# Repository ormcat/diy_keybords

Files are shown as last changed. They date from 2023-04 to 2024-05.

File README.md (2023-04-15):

ErgoFine
====

## 特徴
- 左右分割
- 60%
- カラムスタッカード
- ロープロファイル (Kailh Choc V1 専用)
- 狭ピッチ (18x17 MBK キャップのサイズ)

## 設計のポイント

数字行を設け、キー数に余裕をもたせたロープロファイルな 60% キーボードです。

FR4 とアクリルを積層し、硬い打鍵感を目指しました。
スイッチプレートと基盤の間にはシリコンシートを挟めると音が落ち着くかもしれません。

※基盤製造後に KiCad データを若干調整したため、なにかしら不備があるかもしれません。

---

Designed by ormcat

基盤は [自作キーボード設計入門](https://booth.pm/ja/items/1044084) を読みながら設計しました。  
KiCad シンボル、フットプリントは [foostan/kbd](https://github.com/foostan/kbd) を利用しました。

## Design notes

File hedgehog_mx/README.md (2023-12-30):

Hedgehog (MX)
=======

DIY keyboard "Hedgehog"

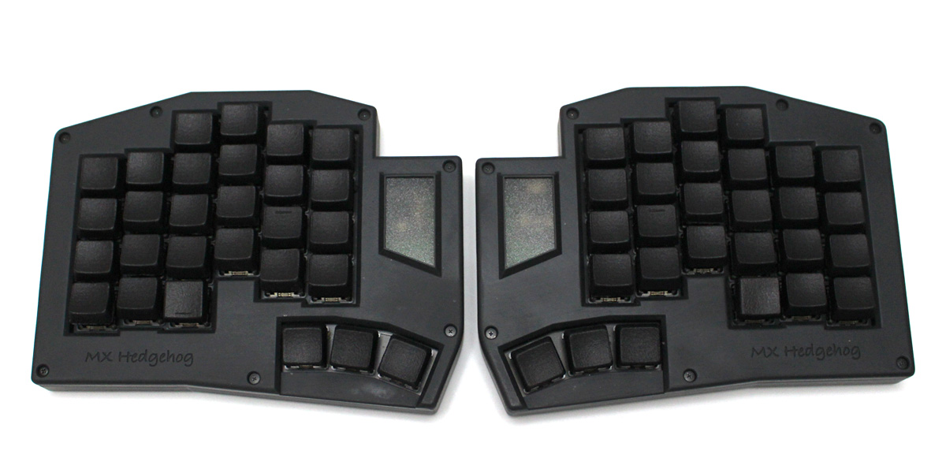
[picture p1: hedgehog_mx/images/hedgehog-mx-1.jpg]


---

## Feature

- Small key pitch (17x16)
- Split
- Size : 60% (56 keys)
- Layout : Coloumn staggered
- Controller board : Waveshare RP2040-Zero
- - Supported firmware : [QMK Firmware](https://docs.qmk.fm/#/) and Vial
- Gasket mount like 3D Printed case

## PCB Image

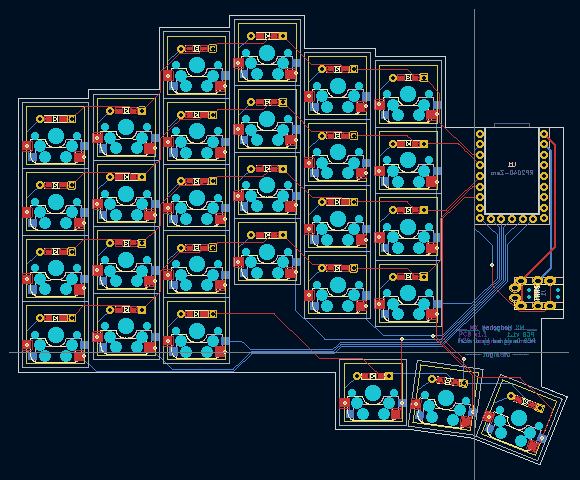
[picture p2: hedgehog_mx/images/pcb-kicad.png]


Designed by KiCad

## CaseImage

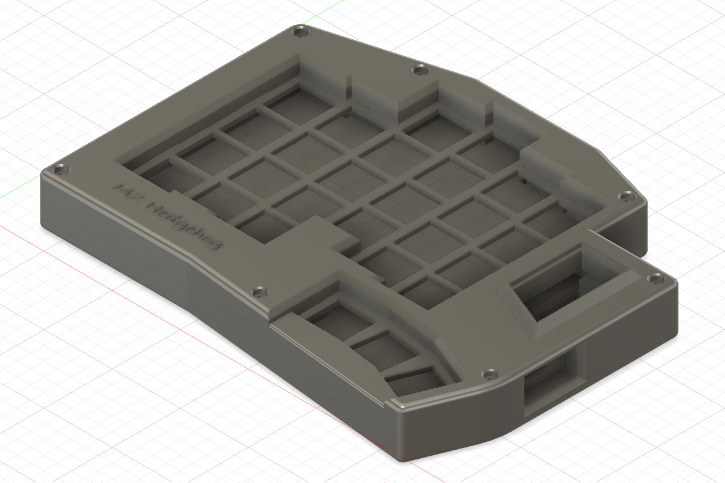
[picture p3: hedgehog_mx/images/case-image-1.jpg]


Designed by FUSION360

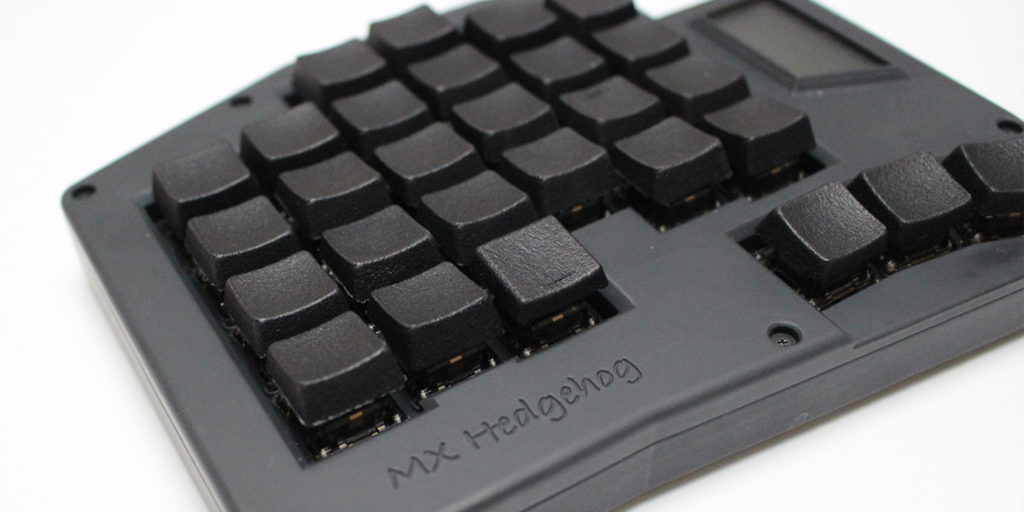
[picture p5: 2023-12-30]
hedgehog_mx/images/hedgehog-mx-4.jpg

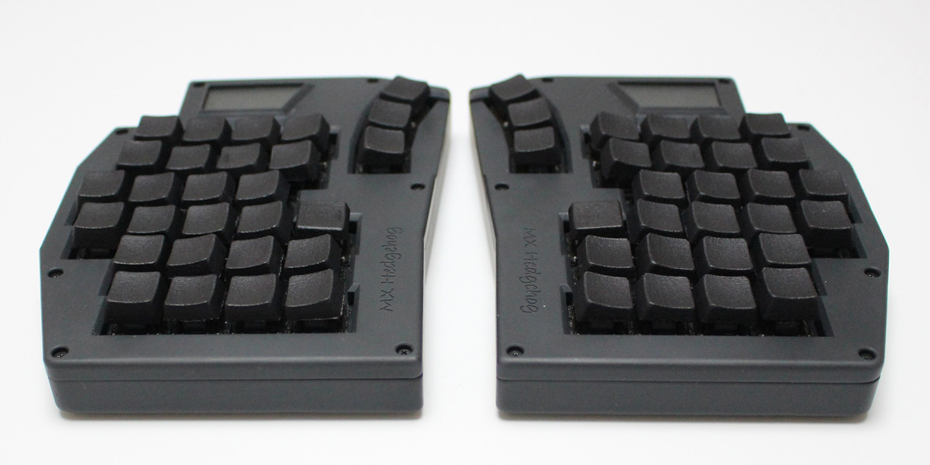
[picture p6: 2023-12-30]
hedgehog_mx/images/hedgehog-mx-2.jpg

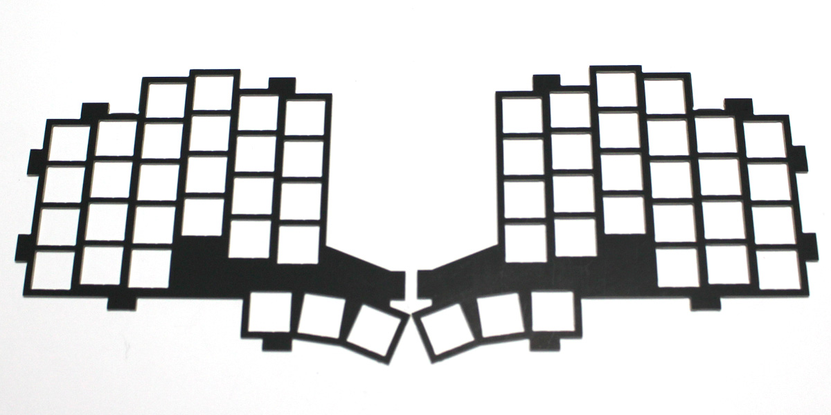
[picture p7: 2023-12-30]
hedgehog_mx/images/switch-plate.jpg

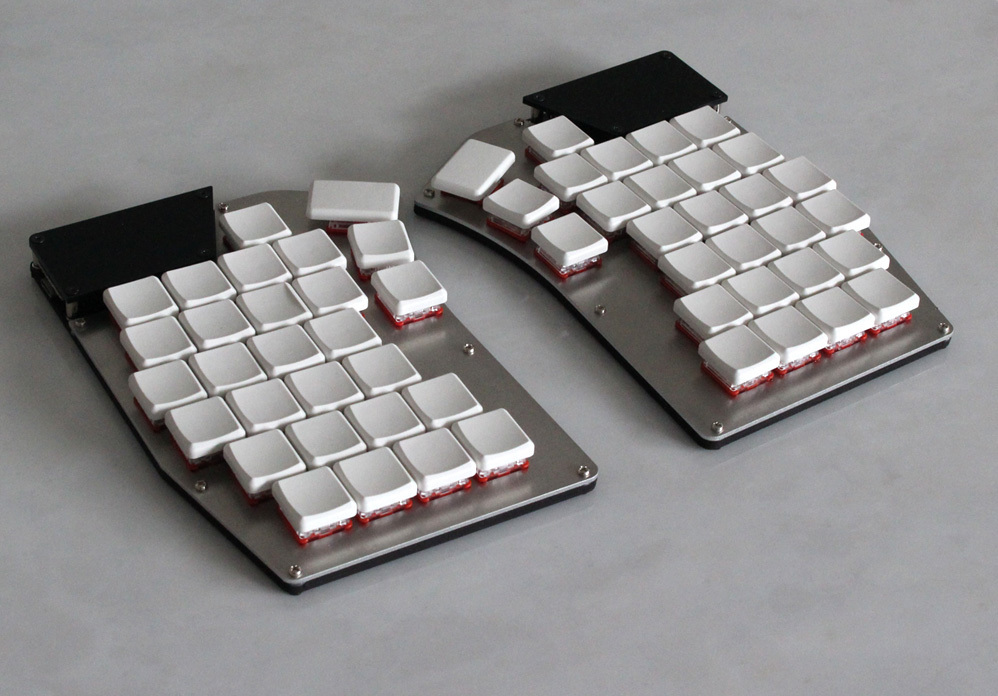
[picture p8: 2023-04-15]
ergo_file/Image/ergofine.jpg

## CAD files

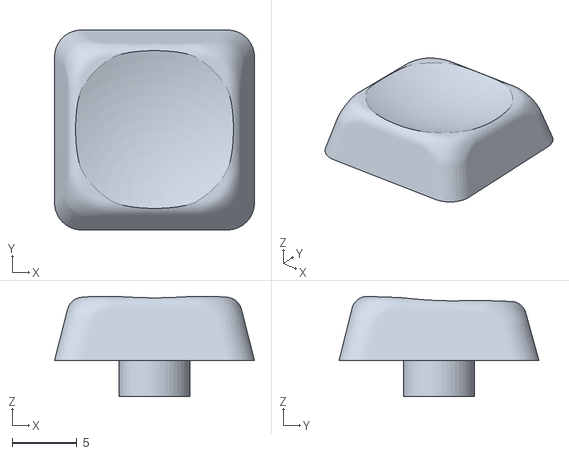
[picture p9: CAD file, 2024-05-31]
3dprinted_keycaps/original-keycap.stl
15.5 x 15.5 x 7.77

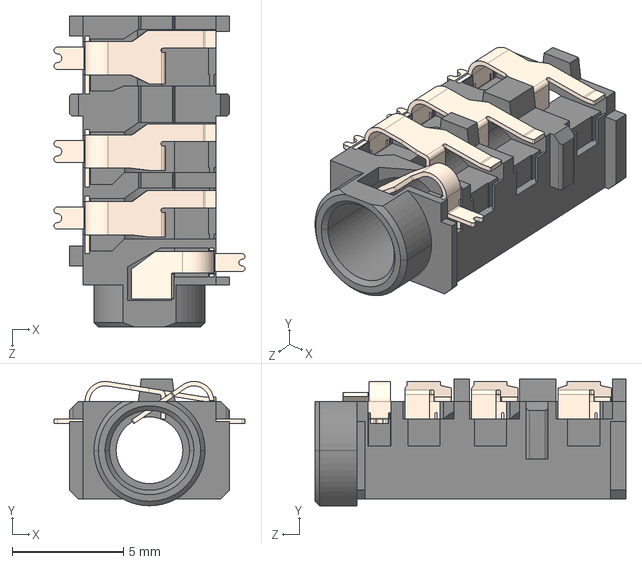
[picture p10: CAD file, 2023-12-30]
ergo_file/Pcb/@lib/Keebio-Parts.pretty-master/3dmodels/CUI_SJ-43614-SMT-TR.step
8.60 x 5.70 x 14.0 mm

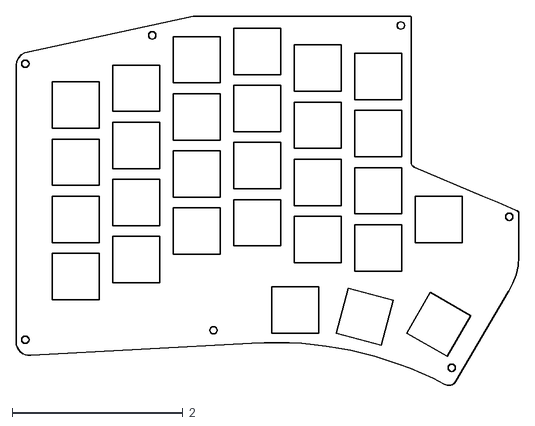
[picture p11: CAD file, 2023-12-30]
ergo_file/PlateData/ErgoFine-SwitchPlate.dxf
5.89 x 4.33

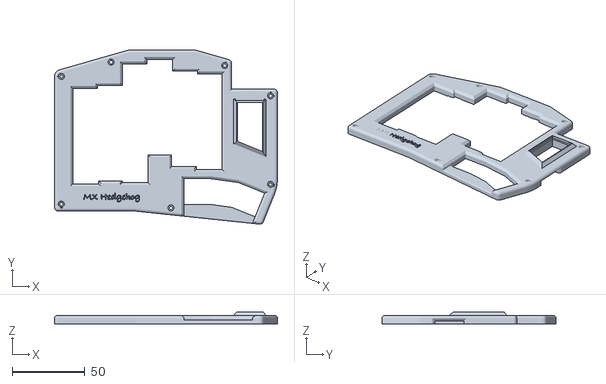
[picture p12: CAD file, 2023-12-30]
hedgehog_mx/case/HedgehogMx-Left-Top.stl
153.5 x 120.0 x 8.50

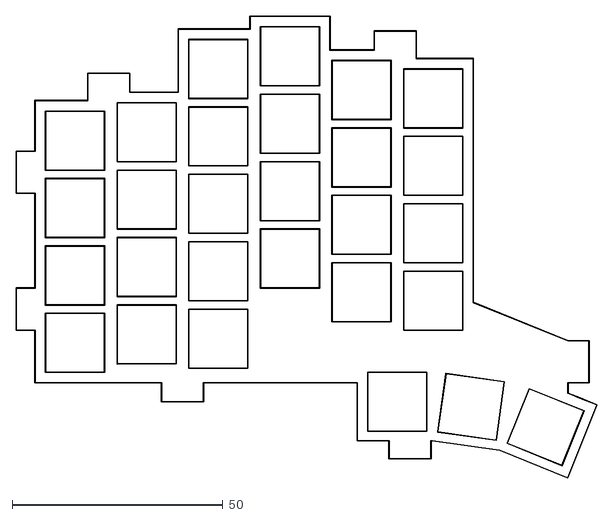
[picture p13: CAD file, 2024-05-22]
hedgehog_mx/plate/Hedgehog-Edge_Cuts.dxf
137.9 x 109.6

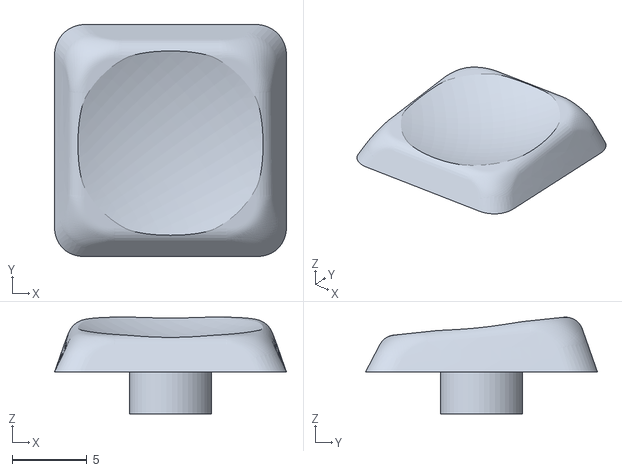
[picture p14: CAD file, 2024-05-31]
3dprinted_keycaps/original-keycap-thumb.stl
15.5 x 15.5 x 6.46

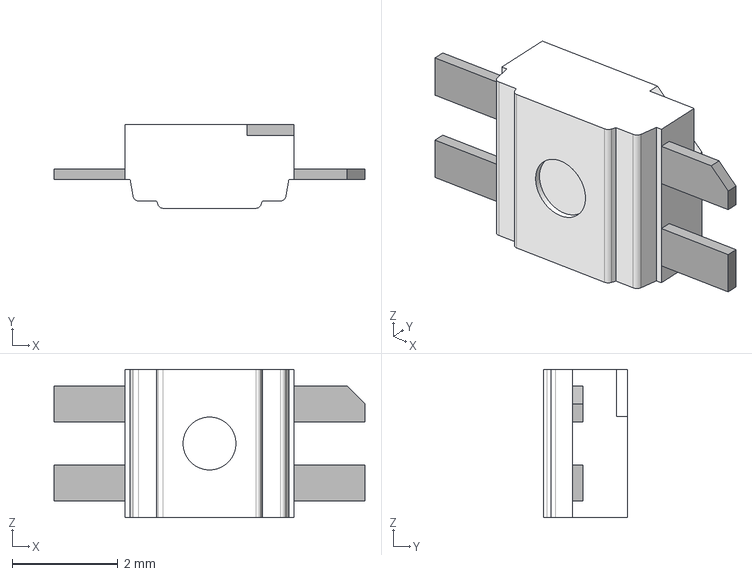
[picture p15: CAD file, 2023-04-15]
ergo_file/Pcb/@lib/Keebio-Parts.pretty-master/3dmodels/SK6812MINI-E v1.step
5.88 x 1.58 x 2.80 mm

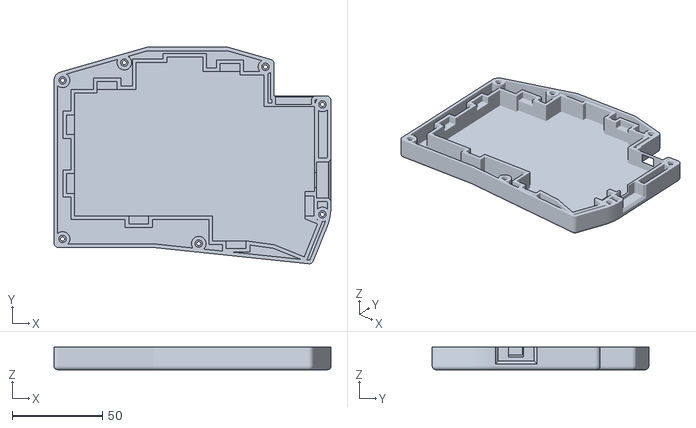
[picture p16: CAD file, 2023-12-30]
hedgehog_mx/case/HedgehogMx-Left-Bottom.stl
153.5 x 120.0 x 12.5

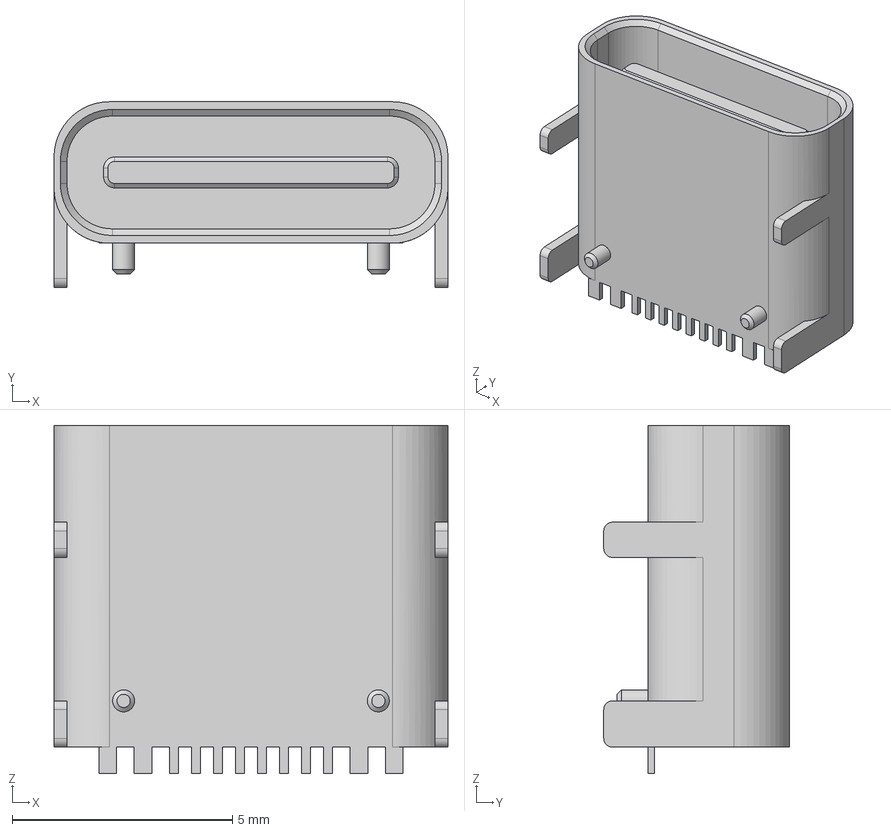
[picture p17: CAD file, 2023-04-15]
ergo_file/Pcb/@lib/Keebio-Parts.pretty-master/3dmodels/HRO TYPE-C-31-M-12.step
8.94 x 4.21 x 7.90 mm

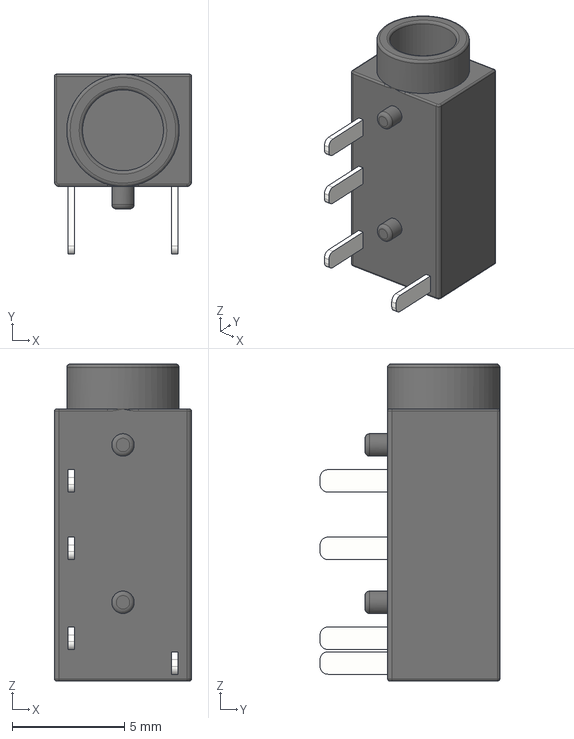
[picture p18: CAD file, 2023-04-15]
ergo_file/Pcb/@lib/Keebio-Parts.pretty-master/3dmodels/PJ-320A.step
6.10 x 8.00 x 14.1 mm

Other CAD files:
hedgehog_mx/case/HedgehogMx-Right-Bottom.stl
hedgehog_mx/case/HedgehogMx-Right-Top.stl

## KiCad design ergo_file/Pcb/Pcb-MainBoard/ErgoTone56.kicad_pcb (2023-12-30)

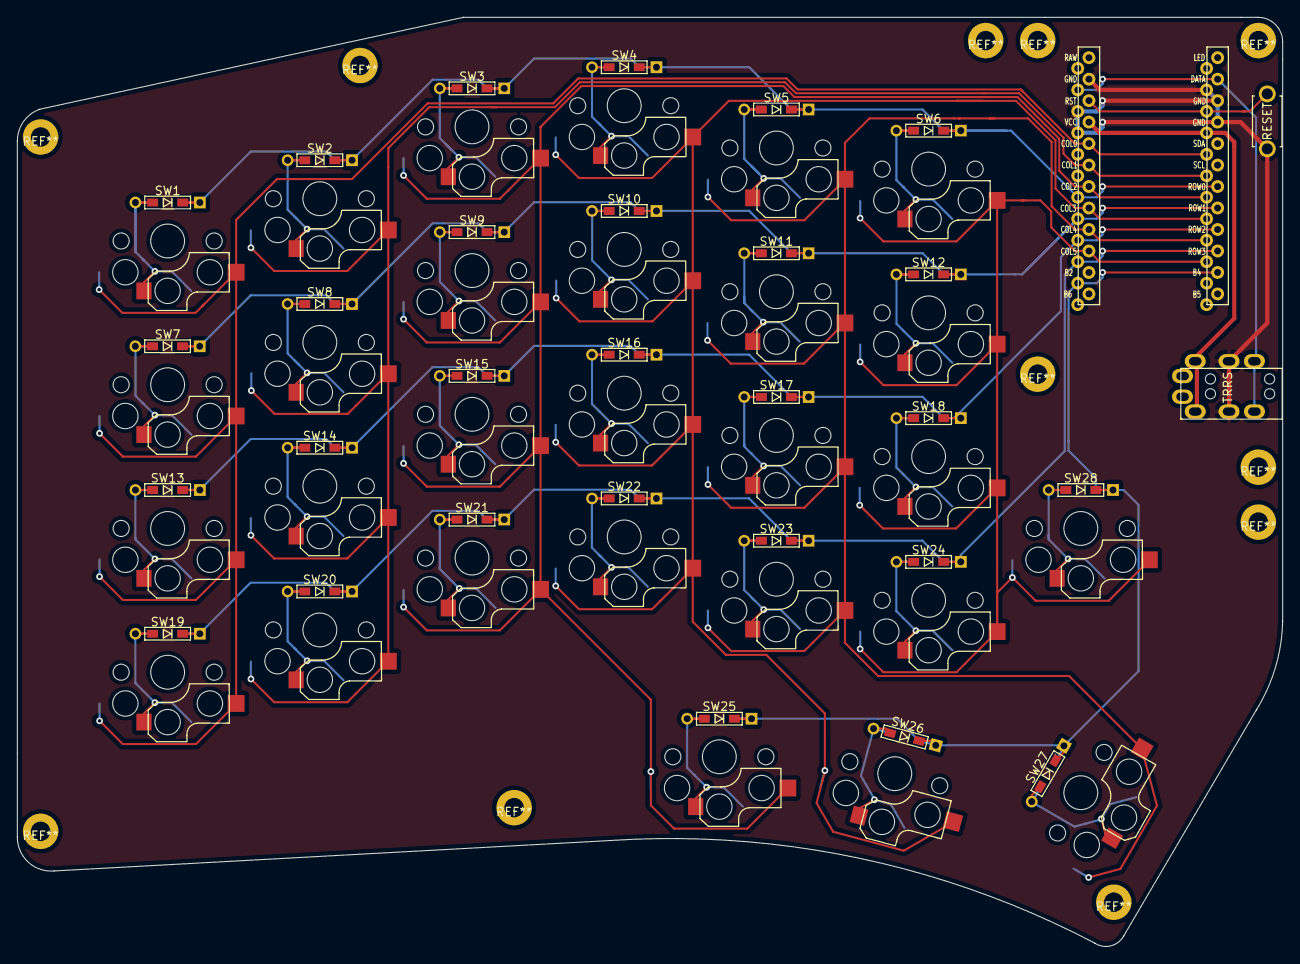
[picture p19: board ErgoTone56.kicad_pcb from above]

Board: 2 copper layers, 149.6 x 109.9 mm, 59 parts (0 on the bottom side), 43 nets.

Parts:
D1, D2, D3, D4, D5, D6, D7, D8, D9, D10, D11, D12, D13, D14, D15, D16, D17, D18, D19, D20, D21, D22, D23, D24, D25, D26, D27, D28: D; D3_TH_SMD
J1: MJ-4PP-9
SW1, SW2, SW3, SW4, SW5, SW6, SW7, SW8, SW9, SW10, SW11, SW12, SW13, SW14, SW15, SW16, SW17, SW18, SW19, SW20, SW21, SW22, SW23, SW24, SW25, SW26, SW28: SW_PUSH; ChocV1_Hotswap_Reverse
SW27: SW_PUSH; ChocV1_Hotswap_Reverse_1.5u
SW29: SW_PUSH; ResetSW
U1: ProMicro; ProMicro_v2

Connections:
GND: J1.C, SW29.2, U1.3, U1.4, U1.23
unnamed: D1.2, SW1.2
unnamed: D2.2, SW2.2
unnamed: D3.2, SW3.2
unnamed: D4.2, SW4.2
unnamed: D5.2, SW5.2
unnamed: D6.2, SW6.2
unnamed: D7.2, SW7.2
unnamed: D8.2, SW8.2
unnamed: D9.2, SW9.2
unnamed: D10.2, SW10.2
unnamed: D11.2, SW11.2
unnamed: D12.2, SW12.2
unnamed: D13.2, SW13.2
unnamed: D14.2, SW14.2
unnamed: D15.2, SW15.2
unnamed: D16.2, SW16.2
unnamed: D17.2, SW17.2
unnamed: D18.2, SW18.2
unnamed: D19.2, SW19.2
unnamed: D20.2, SW20.2
unnamed: D21.2, SW21.2
unnamed: D22.2, SW22.2
unnamed: D23.2, SW23.2
unnamed: D24.2, SW24.2
unnamed: D25.2, SW25.2
unnamed: D26.2, SW26.2
unnamed: D27.2, SW27.2
unnamed: D28.2, SW28.2
VCC: J1.D, U1.21
col0: SW1.1, SW7.1, SW13.1, SW19.1, U1.20
col1: SW2.1, SW8.1, SW14.1, SW20.1, U1.19
col2: SW3.1, SW9.1, SW15.1, SW21.1, SW25.1, U1.18
col3: SW4.1, SW10.1, SW16.1, SW22.1, SW26.1, U1.17
col4: SW5.1, SW11.1, SW17.1, SW23.1, SW27.1, U1.16
col5: SW6.1, SW12.1, SW18.1, SW24.1, SW28.1, U1.15
data: J1.B, U1.2
reset: SW29.1, U1.22
row0: D1.1, D2.1, D3.1, D4.1, D5.1, D6.1, U1.7
row1: D7.1, D8.1, D9.1, D10.1, D11.1, D12.1, U1.8
row2: D13.1, D14.1, D15.1, D16.1, D17.1, D18.1, U1.9
row3: D19.1, D20.1, D21.1, D22.1, D23.1, D24.1, U1.10
row4: D25.1, D26.1, D27.1, D28.1, U1.11

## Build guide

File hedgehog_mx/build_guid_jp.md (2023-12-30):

Hedgehog (MX) ビルドガイド
=======

## 注意

### 取り付け位置に注意

当モデルの PCB はリバーシブルです。

各パーツの実装面を誤ると動作しません。  
とくに __コントローラーボードのはんだ付けが厄介__ です。

### ケースデータが干渉する可能性

USB と TRRS 用の穴は、それほど余裕がありません。
接続口写真を掲載します。

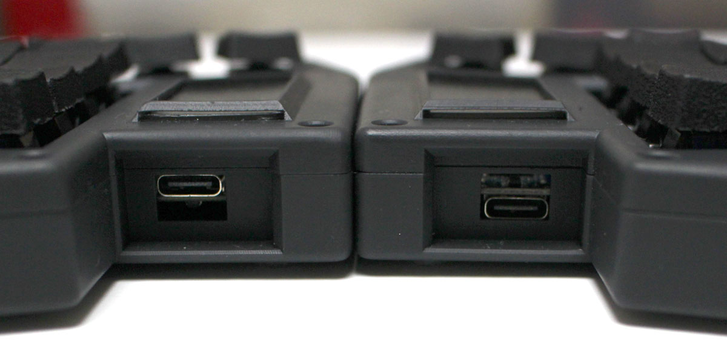
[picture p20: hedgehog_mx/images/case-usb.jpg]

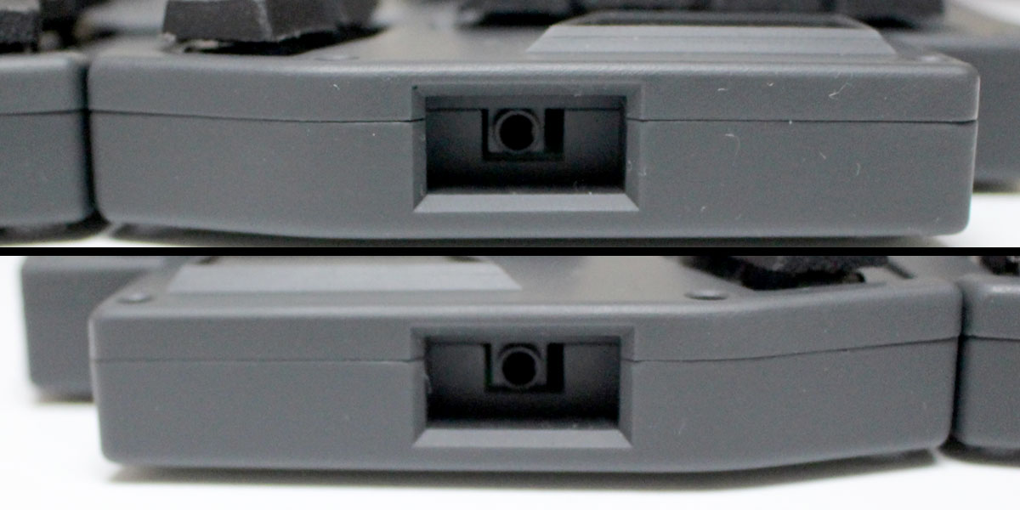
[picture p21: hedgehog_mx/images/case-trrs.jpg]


プリント方法やクッション材の高さによってはケースとの干渉が発生するかもしれません。

なお作者は JLCPCB のブラックレジンでケースを作りました。

### 窓のあるデザイン

コントローラーボード部分には窓があります。  
窓には 1.0 - 1.2 mm 程度の板をカットして差し込みます。

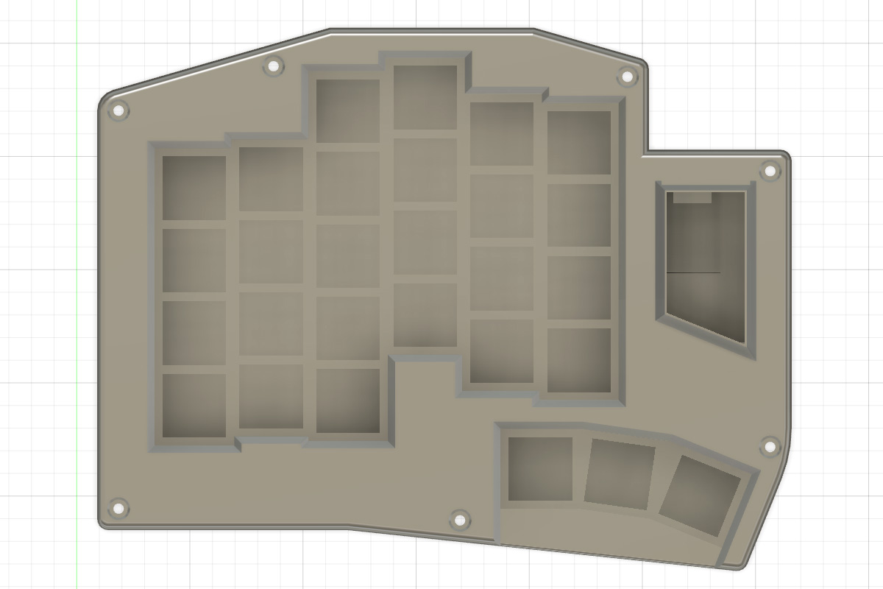
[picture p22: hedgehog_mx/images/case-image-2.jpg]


BOOT 、 RESET ボタンを操作する想定で穴を開けましたが、右手側はボタンが裏面になるため無意味でした。

デザインとしてお楽しみください。

なお、まだ図面を作成していません。
作者は 100 均で 1.0mm のプラ板を買ってきてフリーハンドでカットしたものを装着しています。

## 組み立てフロー

- 実装面確認
- ダイオードのはんだ付け
- スイッチソケットのはんだ付け
- コントローラーボードのはんだ付け
- TRRS ケーブルジャックのはんだ付け
- ファームウェア書き込み
- ケースとりつけ

## パーツリスト

|名称|数量|備考|
|:--|--:|:--|
|PCB|2||
|スイッチプレート|2||
|Waveshare RP2040-Zero|2||
|ダイオード|56|表面実装タイプ|
|スイッチソケット|56|MX スイッチ用|
|TRRS ジャック|2||
|MX 互換スイッチ|56||
|キーキャップ|56|0.8U|
|USB Type-C|1||
|TRRS ケーブル|1||

標準 3D プリントケースを利用する場合は次が必要です

|名称|数量|備考|
|:--|--:|:--|
|M2 スペーサー 10mm|14||
|M2 ネジ|28|長さは 5mm を推奨|
|クッション材|適量|3.0mm 厚 1.5mm 厚の種類。カットできるもの|
|クッションゴム|適量|底にとりつけるもの|

## 組み立てよう

### 実装面確認

PCB を左右 2 枚並べ、できあがりをイメージしましょう。

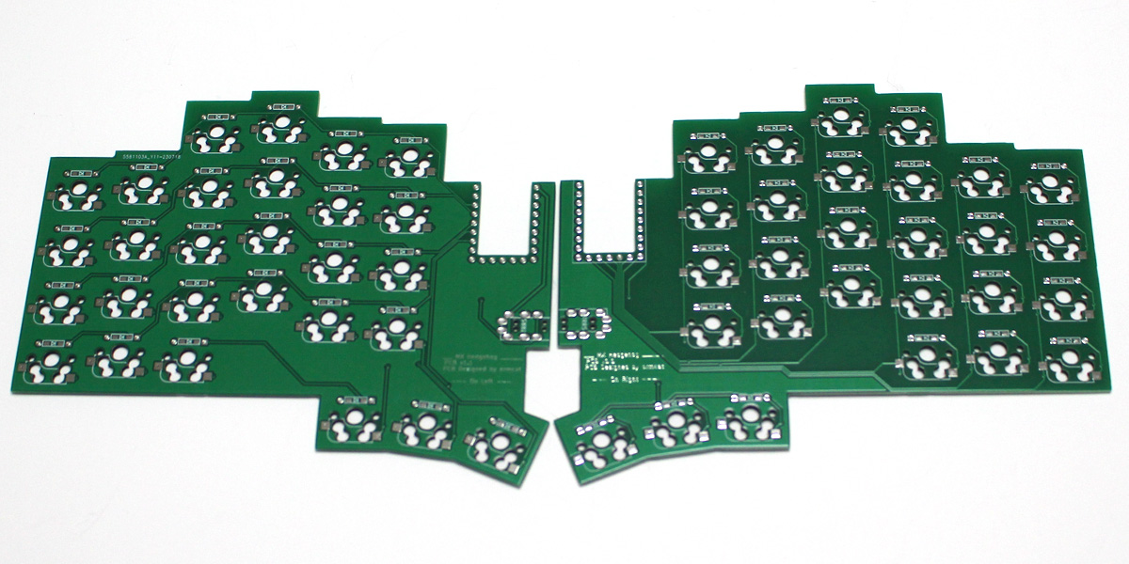
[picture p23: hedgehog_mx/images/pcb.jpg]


はんだ付け面を間違えないように、マスキングテープを貼って書き記しておくことを推奨します。

### ダイオードのはんだ付け

_裏面_ にダイオードをはんだ付けします。

ダイオードの向きに注意してください。

### スイッチソケットのはんだ付け

_裏面_ にスイッチソケットをはんだ付けします。

### コントローラーボードのはんだ付け

当キットの最難関部分です。

写真のとおりに配置してください。裏、表を誤るとケースに干渉します。

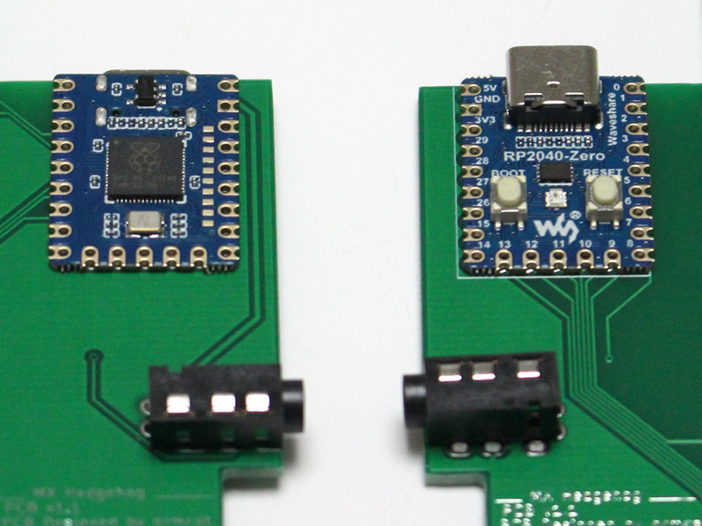
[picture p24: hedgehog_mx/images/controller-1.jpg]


コントローラーボードのはんだ付けはリカバリが困難です。  
作者でも 2 度間違えました。

向き、取り付け面は 3 回以上確認することを推奨します。

#### 左手用

_BOOT ボタンのある面を下_ にし、 PCB の表面に配置します。

#### 右手用

_BOOT ボタンのある面を上_ にし、 PCB の表面に配置します。

#### コントローラーボードのはんだ付け

向き、取り付け面を確認したら、マスキングテープで仮止めし、はんだ付けを行います。

PIN の端にはんだごてを当て、多めにはんだを流し入れます。

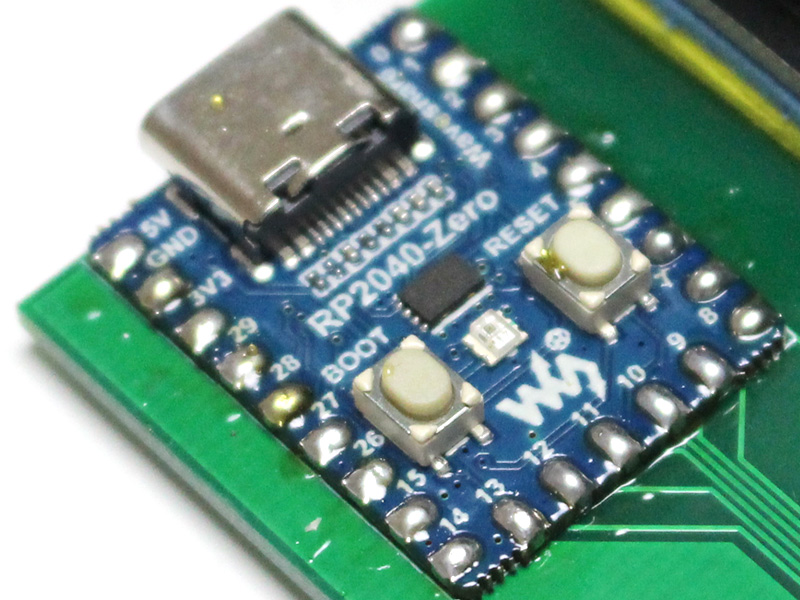
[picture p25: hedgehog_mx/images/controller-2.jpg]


裏面に少し山ができる程度が目安です。

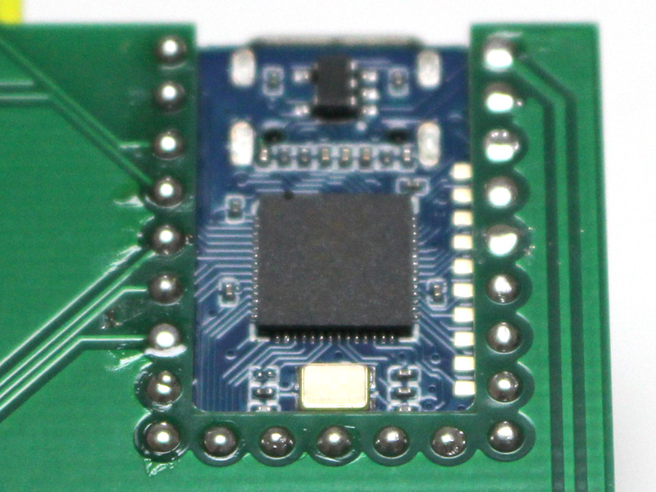
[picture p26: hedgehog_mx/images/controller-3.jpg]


__このはんだ付けは難しい__ です。  
変な設計でごめんなさい。

### TRRS ジャックのはんだ付け

_表面_ に TRRS ジャックを取り付けます。

マスキングテープで仮止めし、PCB をひっくり返して足をはんだ付けします。

### ファームウェア書き込み

次手順で書き込みます。

- パソコンに接続する
- BOOT ボタンを押しながら RESET ボタンを押す
- RESET ボタンを戻す
- BOOT ボタンを戻す
- マウントされた USB マスストレージ (RPI-RP2) に、 UF2 をドラッグ & ドロップする。

### 組み立て



トップケースイメージ

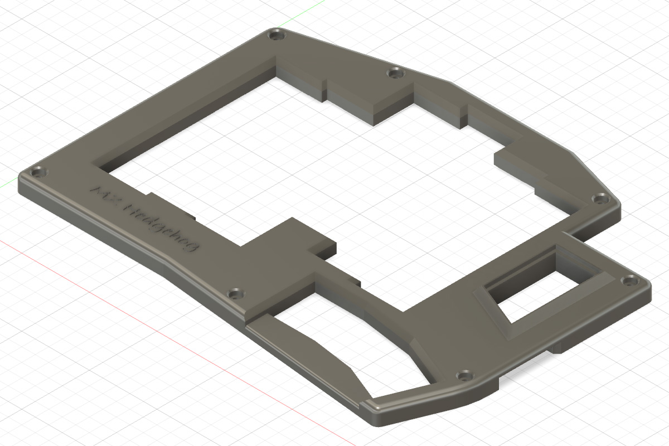
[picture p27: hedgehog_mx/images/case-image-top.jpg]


ボトムケースイメージ

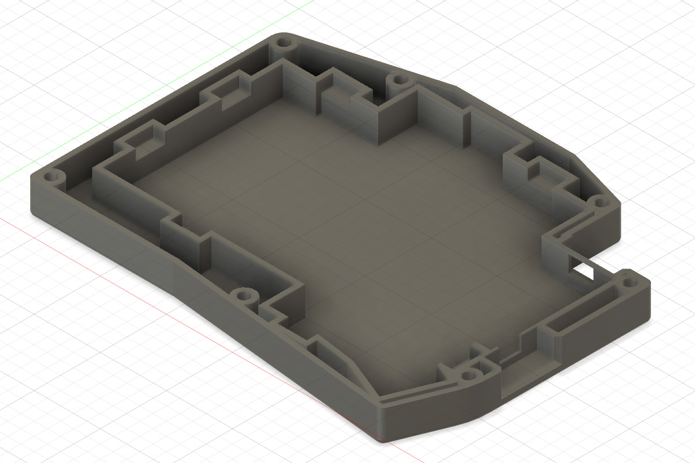
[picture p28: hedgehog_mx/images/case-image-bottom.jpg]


#### クッションを貼る

スイッチプレートとケースの間にクッションを挟む、ガスケットマウント風マウントです。

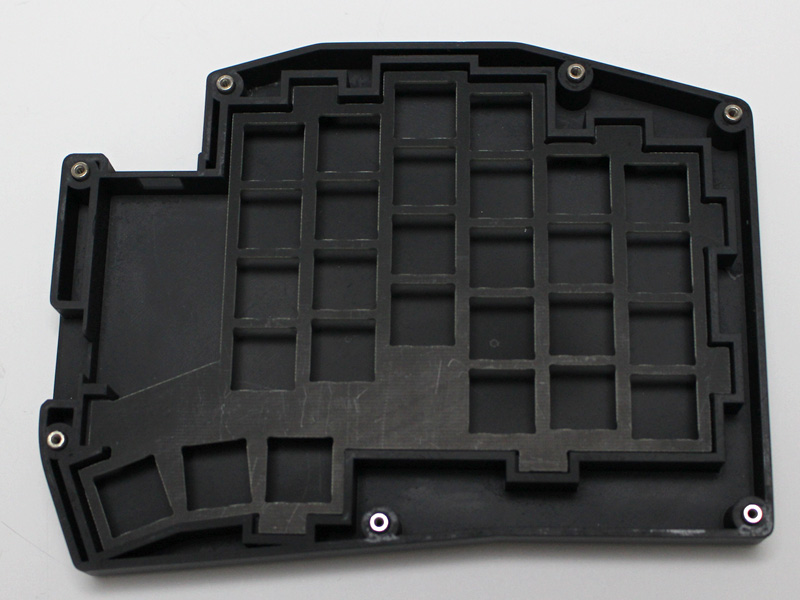
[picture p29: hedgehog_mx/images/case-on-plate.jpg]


ポロンゴムを細長く切り、スイッチプレート、ケースの所定位置に貼り付けます。

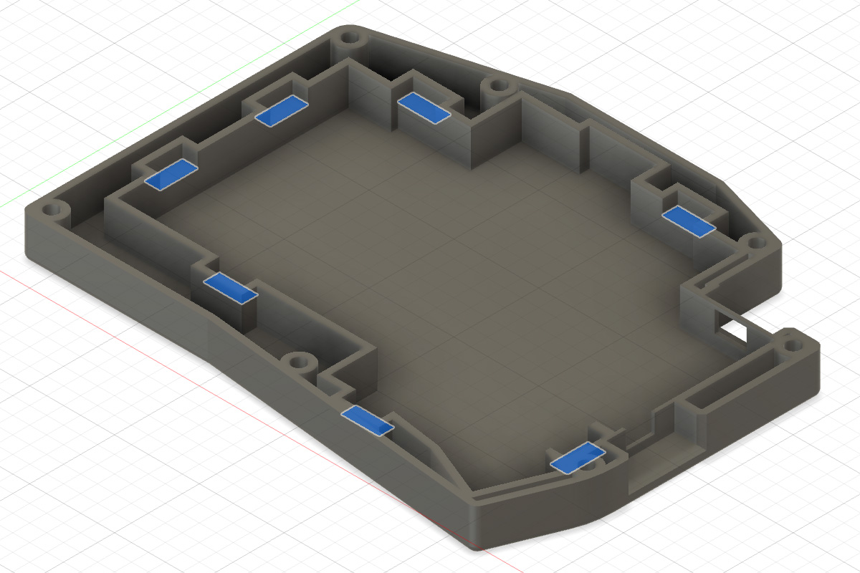
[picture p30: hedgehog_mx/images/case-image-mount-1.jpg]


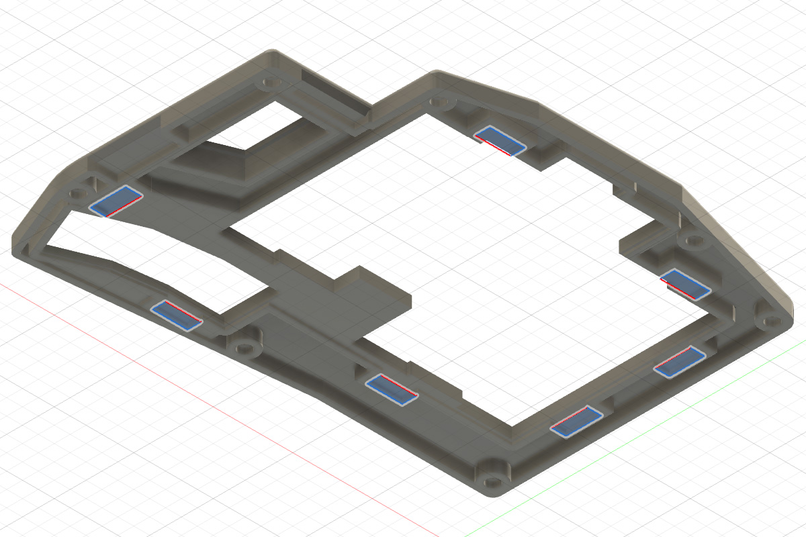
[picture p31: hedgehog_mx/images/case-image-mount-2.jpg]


なお、ボトムケースのマウント部からスイッチプレート下面までの位置は _3.0mm_ で設計しました。  
対して、スイッチプレート上面からトップケースまでは _1.0 〜 1.5mm_ です。

ボトムケース、トップケースと、スイッチプレートの下のみの 3 面にクッションをはれば、1.5mm 厚の一種類で間に合うと思います。（未検証。ある程度厚みがあっても吸収するはず？的な考え）

作者はスイッチプレートと PCB の間にフォームなどを挟んでおり、スイッチプレート耳部分にもフォームを出すことで、ボトムケース、スイッチプレートのクッションとして利用しています。

#### スイッチを取り付ける

PCB にスイッチプレートを重ね、スイッチをすべて取り付けます。

#### ケース

ボトムケースのスリットに M2 スペーサーを入れ、裏側からネジで固定します。

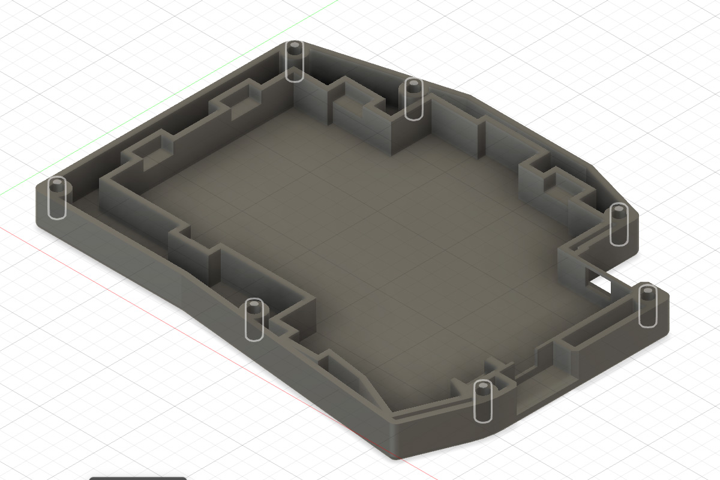
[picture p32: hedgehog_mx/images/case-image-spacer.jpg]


次に、ボトムケースに PCB を載せます。  
USB 接続端子を先に穴に通してから全体を乗せ瑠葉にしてください。

PCB が収まったらトップケースを上からはめ、ネジ止めします。

---

おめでとうございます。  
完成です。

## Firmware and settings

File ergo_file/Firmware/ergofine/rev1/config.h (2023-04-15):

/*
Copyright 2018 Pierre Constantineau <jpconstantineau@gmail.com>

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
You should have received a copy of the GNU General Public License
along with this program.  If not, see <http://www.gnu.org/licenses/>.
*/

#pragma once

/* USB Device descriptor parameter */
#define VENDOR_ID       0x4F45 // OE Ormcat ErgoFine
#define PRODUCT_ID      0x4546 // ET ErgoFine
#define DEVICE_VER      0x0100
#define MANUFACTURER    ormcat
#define PRODUCT         ErgoFine Keyboard

/* key matrix size */
// Rows are doubled-up
#define MATRIX_ROWS 10
#define MATRIX_COLS 6

// wiring of each half
#define MATRIX_ROW_PINS { D4, C6, D7, E6, B4 }
#define MATRIX_COL_PINS { F4, F5, F6, F7, B1, B3 }

/* COL2ROW or ROW2COL */
#define DIODE_DIRECTION COL2ROW

/* define if matrix has ghost */
//#define MATRIX_HAS_GHOST

/* number of backlight levels */
// #define BACKLIGHT_LEVELS 3

/* Set 0 if debouncing isn't needed */
#define DEBOUNCE 5

/* Mechanical locking support. Use KC_LCAP, KC_LNUM or KC_LSCR instead in keymap */
#define LOCKING_SUPPORT_ENABLE
/* Locking resynchronize hack */
#define LOCKING_RESYNC_ENABLE

/* serial.c configuration for split keyboard */
#define SOFT_SERIAL_PIN D2

/*
#define BACKLIGHT_PIN B5
#define BACKLIGHT_LEVELS 5
*/

/* ws2812 RGB LED 
#define RGB_DI_PIN D3
#define RGBLED_NUM 12    // Number of LEDs
*/

/*
 * Feature disable options
 *  These options are also useful to firmware size reduction.
 */

/* disable debug print */
// #define NO_DEBUG

/* disable print */
// #define NO_PRINT

/* disable action features */
//#define NO_ACTION_LAYER
//#define NO_ACTION_TAPPING
//#define NO_ACTION_ONESHOT
//#define NO_ACTION_MACRO
//#define NO_ACTION_FUNCTION

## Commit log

2023-04-15 New Keyboard
    [CUI_SJ-43614-SMT-TR.step, ErgoFine-SwitchPlate.dxf, ErgoTone56-Middle.kicad_pcb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]
2023-12-30 chore rm dir
    [CUI_SJ-43614-SMT-TR.step, ErgoFine-SwitchPlate.dxf, ErgoTone56-Middle.kicad_pcb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]
2023-12-30 add hedgehog mx
    [HedgehogMx-Left-Bottom.stl, HedgehogMx-Left-Top.stl, HedgehogMx-Right-Bottom.stl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]
2024-05-22 Hedgehog MX add Switch Plate SVG/DXF
    [Hedgehog-Edge_Cuts.dxf]
2024-05-31 keycap sample stl
    [original-keycap-thumb.stl, original-keycap.stl]

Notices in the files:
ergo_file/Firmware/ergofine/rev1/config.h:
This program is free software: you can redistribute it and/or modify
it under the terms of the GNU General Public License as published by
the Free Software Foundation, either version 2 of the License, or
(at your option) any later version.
